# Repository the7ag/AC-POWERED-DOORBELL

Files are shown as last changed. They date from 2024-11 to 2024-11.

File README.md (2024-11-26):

# ESP32 AC Powered with Node.js API to data log

This project uses an **ESP32** microcontroller to send signal data (when a digital pin goes HIGH) to a **Node.js** backend API. The backend uses **MongoDB** to store user data and the signal data. The ESP32 device sends the data to the server only when the signal on a specific pin goes HIGH, with API key-based authentication.

## Table of Contents
- [Project Overview](#project-overview)
- [Hardware Requirements](#hardware-requirements)
- [Software Requirements](#software-requirements)
- [Project Setup](#project-setup)
- [Backend API Structure](#backend-api-structure)
- [ESP32 Setup](#esp32-setup)
- [Database Schema](#database-schema)
- [API Endpoints](#api-endpoints)
- [Testing](#testing)
- [Images](#images)

## Project Overview
This project allows you to authenticate a user and send digital signal data from the ESP32 to a backend server using an API key. When the pin state of a digital input (connected to pin 13) goes HIGH, the ESP32 sends a POST request to the backend API with a timestamp and pin state.

The backend server:
1. Validates the API key sent with each request.
2. Stores signal data in the **SignalData** collection in MongoDB.
3. Associates the data with a user based on their **unique ID** and **API key**.

## Hardware Requirements
- **ESP32 Development Board**
- **Jumper wires** for connecting to external pins
- A breadboard (optional)

### Connections:
- **Pin 13**: Connected to a digital signal source (e.g., a button or sensor)

## Software Requirements
- **Arduino IDE** with the ESP32 board package installed
- **Node.js** and **npm** for running the backend server
- **MongoDB** (local or cloud) to store user and signal data
- **Arduino JSON** library for handling JSON data in the ESP32

## Project Setup

### 1. Clone the Repository
Clone the repository to your local machine:
```bash
git clone https://github.com/yourusername/esp32-signal-data-logger.git
```

### 2. Set Up the Backend API

#### Backend Requirements:
- **Node.js** and **npm** installed
- **MongoDB** running locally or using a cloud service (e.g., MongoDB Atlas)

To set up the backend:
1. Navigate to the `backend` directory:
   ```bash
   cd backend
   ```

2. Install the required dependencies:
   ```bash
   npm install
   ```

3. Start the backend server:
   ```bash
   npm start
   ```

The backend API will be accessible at `http://localhost:5000`.

### 3. Set Up the ESP32

#### ESP32 Code:
1. Open the Arduino IDE and set the board to **ESP32**.
2. Install the **ArduinoJson** library using the Library Manager.
3. Open the ESP32 code, modify the Wi-Fi credentials and backend URL as needed.
4. Upload the code to the ESP32.

### 4. Configure MongoDB
Ensure that MongoDB is running, and update the database connection settings in the backend code (if necessary).

## Backend API Structure

The backend consists of two main collections in MongoDB:
1. **Users**: Stores the user's `uniqueID` and their `apiKey`.
2. **SignalData**: Stores the signal data, including the `timestamp` and `pinState`, linked to the user by their `uniqueID`.

### Database Models:
#### User Schema:
- **uniqueID**: A unique identifier for each user (e.g., from ESP32).
- **apiKey**: A unique API key for the user.

#### SignalData Schema:
- **userID**: The `uniqueID` of the user who owns the signal data.
- **timestamp**: The timestamp when the pin state went HIGH.
- **pinState**: The state of the pin (HIGH/LOW).

## API Endpoints

### 1. **Authentication (POST /auth)**
- **Description**: Authenticates the user and returns an API key.
- **Request Body**:
  ```json
  {
    "unique_id": "USER_UNIQUE_ID"
  }
  ```
- **Response**:
  ```json
  {
    "api_key": "USER_API_KEY"
  }
  ```

### 2. **Save Signal Data (POST /data)**
- **Description**: Saves the signal data when the pin goes HIGH.
- **Request Headers**:
  - **API-Key**: The user's API key.
- **Request Body**:
  ```json
  {
    "timestamp": "timestamp_value",
    "pin_state": "HIGH"
  }
  ```
- **Response**:
  ```json
  {
    "message": "Signal data saved successfully"
  }
  ```

## Testing

### 1. Testing the API:
You can use tools like **Postman** or **curl** to test the API endpoints.

- **Authenticate User**: Send a `POST` request to `/auth` with the `unique_id`.
- **Submit Signal Data**: Send a `POST` request to `/data` with the API key in the headers and the signal data in the body.

### 2. Testing the ESP32:
- Once the ESP32 is running, it will automatically connect to the Wi-Fi, authenticate with the backend, and send signal data when the digital pin goes HIGH.

## Images

### 1. ESP32 Pin Connection Diagram

### 2. Entire Board


## License
This project is licensed under the MIT License - see the [LICENSE](./LICENSE) file for details.

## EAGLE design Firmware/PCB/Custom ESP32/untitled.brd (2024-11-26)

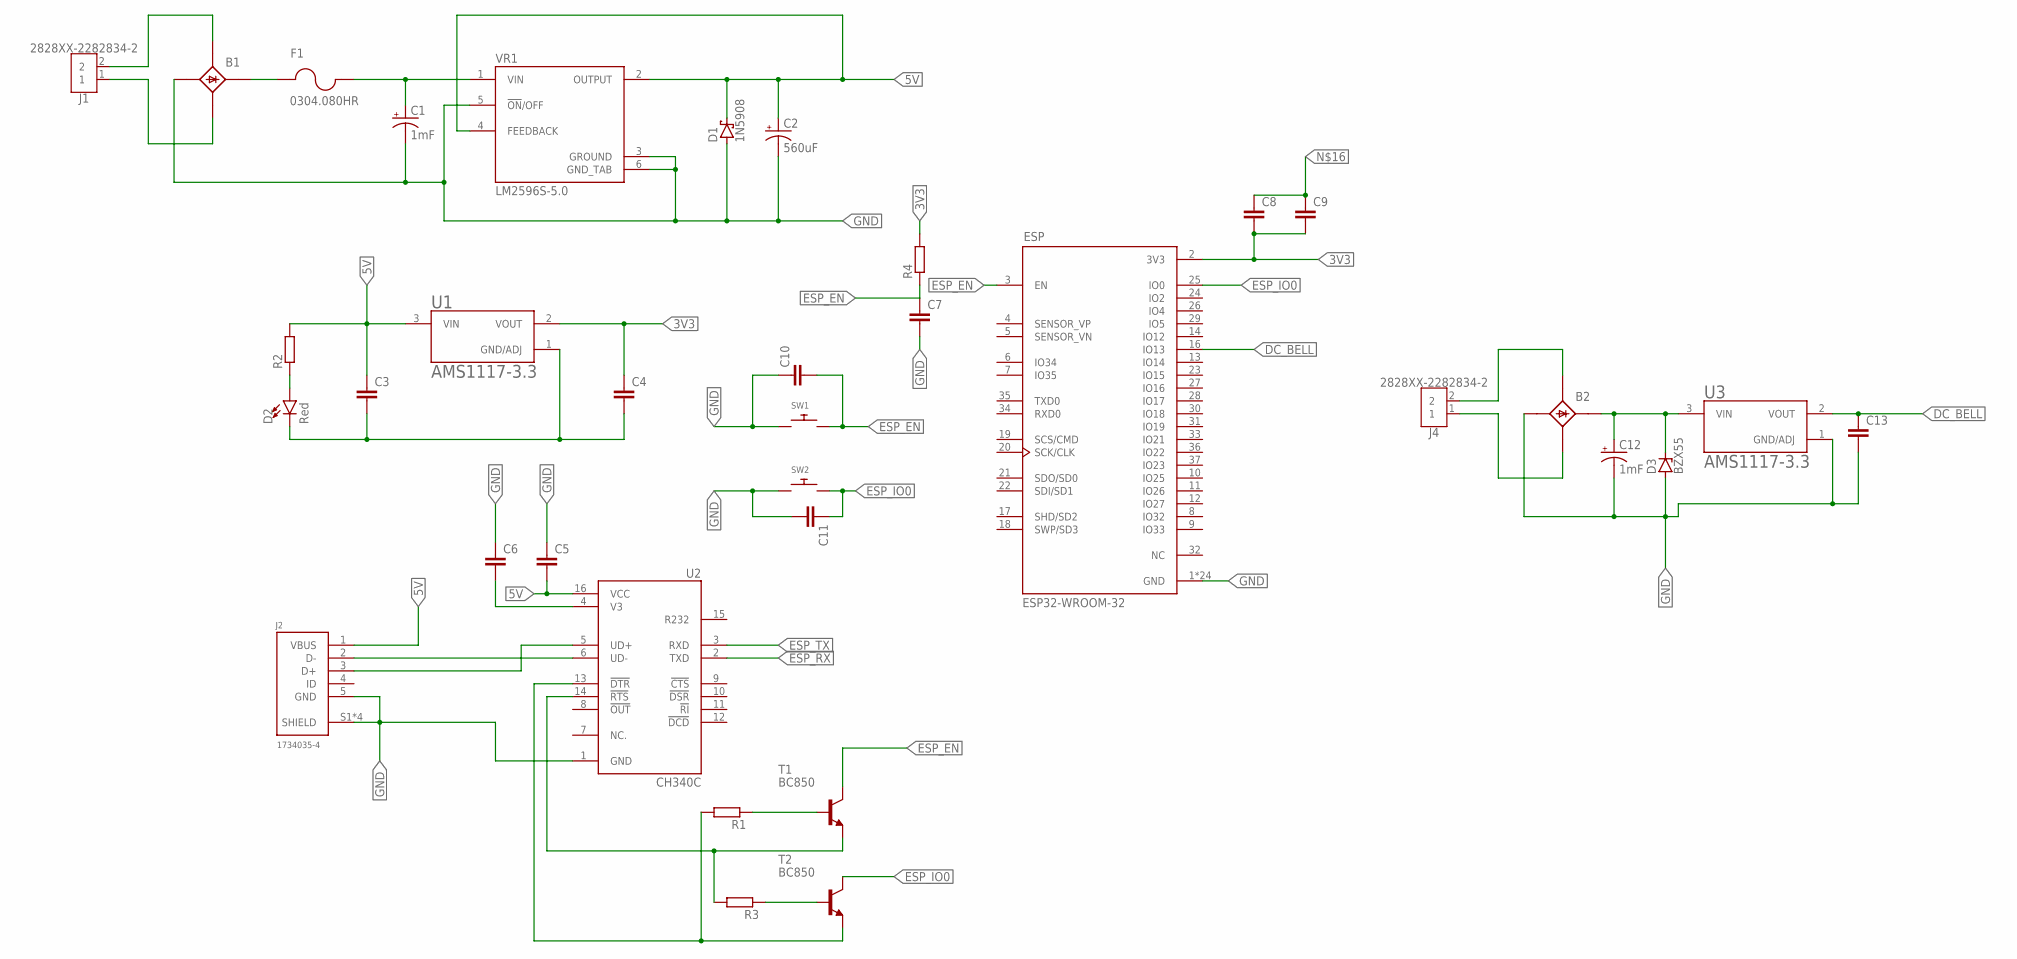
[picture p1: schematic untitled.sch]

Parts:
B1, B2: B25A-
C1, C12: 1mF; CPOL-RADIAL-5MM-10MM
C2: 560uF; PANASONIC_G
C3, C4, C5, C6, C7, C8, C9, C10, C11, C13: C-EUC1206K; C1206K
D1: 1N5908; C4111-15
D2: Red; LED-0603
D3: BZX55; DO35Z10
ESP: ESP32-WROOM-32; MODULE_ESP32-WROOM-32
F1: 0304.080HR
J1, J4: 2828XX-2282834-2; TERMBLK_254-2N
J2: 1734035-4
R1, R2, R3, R4: R-EU_R5025W; R5025W
SW1, SW2: SWITCH_PUSHBUTTONSOFTTOUCHSMD_SJ; PUSHBUTTON_SMD_SJ
T1, T2: BC850; SOT23
U1, U3: AMS1117-3.3; SOT229P700X180-4N
U2: CH340C; SOIC127P600X180-16N
VR1: LM2596S-5.0; TO170P1524X483-6N

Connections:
3V3: C4.1, C8.2, C9.2, ESP.2 (3V3), R4.2, U1.2 (VOUT)
5V: C2.+, C3.1, C5.2, D1.C, J2.1 (VBUS), R2.2, U1.3 (VIN), U2.16 (VCC), VR1.2 (OUTPUT), VR1.4 (FEEDBACK)
DC_BELL: C13.1, ESP.16 (IO13), U3.2 (VOUT)
ESP_EN: C7.1, C10.2, ESP.3 (EN), R4.1, SW1.P$2, T1.3 (C)
ESP_IO0: C11.1, ESP.25 (IO0), SW2.P$2, T2.3 (C)
ESP_RX: U2.2 (TXD)
ESP_TX: U2.3 (RXD)
GND: B1.-1 (-), B2.-1 (-), C1.-, C2.-, C5.1, C6.1, C7.2, C10.1, C11.2, C12.-, C13.2, D1.A, D3.A, ESP.1 (GND), ESP.15 (GND), ESP.38 (GND), ESP.39_1 (GND), ESP.39_2 (GND), ESP.39_3 (GND), ESP.39_4 (GND), ESP.39_5 (GND), ESP.39_6 (GND), ESP.39_7 (GND), ESP.39_8 (GND), ESP.39_9 (GND), ESP.39_10 (GND), ESP.39_11 (GND), ESP.39_12 (GND), ESP.39_13 (GND), ESP.39_14 (GND), ESP.39_15 (GND), ESP.39_16 (GND), ESP.39_17 (GND), ESP.39_18 (GND), ESP.39_19 (GND), ESP.39_20 (GND), ESP.39_21 (GND), J2.5 (GND), J2.S1 (SHIELD), J2.S2 (SHIELD), J2.S3 (SHIELD), J2.S4 (SHIELD), SW1.P$1, SW2.P$1, U2.1 (GND), U3.1 (GND/ADJ), VR1.3 (GROUND), VR1.5 (!ON!/OFF), VR1.6 (GND_TAB)
unnamed: B1.AC1- (AC1), J1.2
unnamed: B1.AC2- (AC2), J1.1
unnamed: B1.+1 (+), F1.1
unnamed: C1.+, F1.2, VR1.1 (VIN)
unnamed: D2.A, R2.1
unnamed: C3.2, C4.2, D2.C, U1.1 (GND/ADJ)
unnamed: J2.3 (D+), U2.5 (UD+)
unnamed: J2.2 (D-), U2.6 (UD-)
unnamed: B2.AC1- (AC1), J4.2
unnamed: B2.AC2- (AC2), J4.1
unnamed: C6.2, U2.4 (V3)
unnamed: R1.1, T1.1 (B)
unnamed: R3.1, T2.1 (B)
unnamed: R3.2, T1.2 (E), U2.14 (!RTS)
unnamed: R1.2, T2.2 (E), U2.13 (!DTR)
unnamed: C8.1, C9.1
unnamed: B2.+1 (+), C12.+, D3.C, U3.3 (VIN)

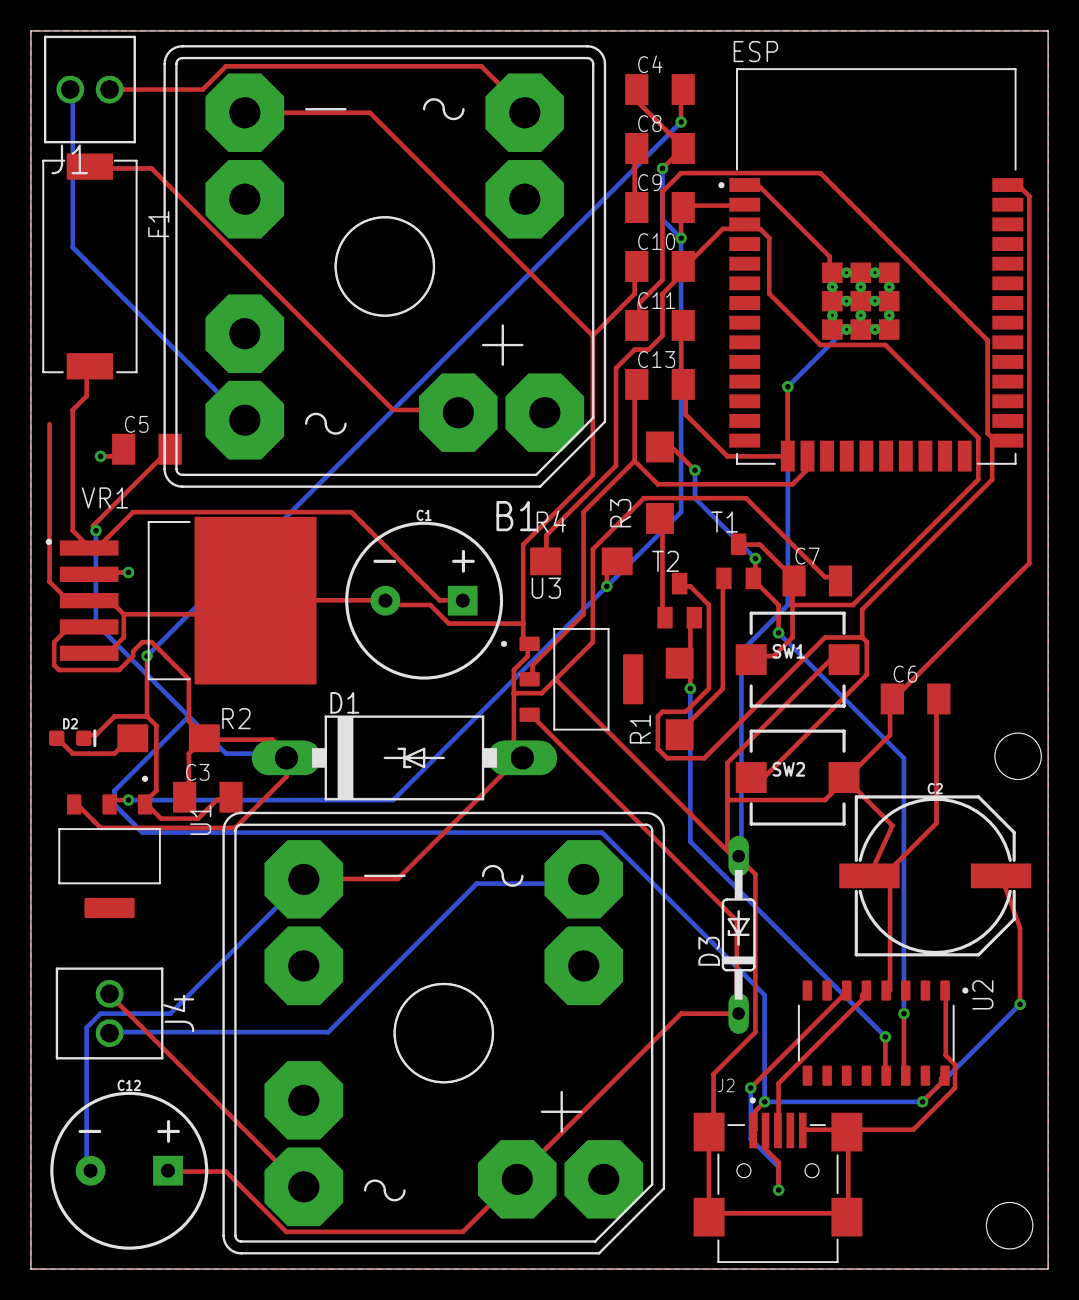
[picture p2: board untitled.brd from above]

Board: 2 copper layers, 65.7 x 80.0 mm, 35 parts (0 on the bottom side), 23 nets.

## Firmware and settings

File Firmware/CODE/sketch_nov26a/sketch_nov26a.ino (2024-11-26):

#include <WiFi.h>
#include <HTTPClient.h>
#include <ArduinoJson.h>
#include "time.h"
#include <esp_sleep.h>

const char* ssid = "your_wifi_ssid";
const char* password = "your_wifi_password";

const char* authURL = "http://192.168.1.1:5000/auth";
const char* dataURL = "http://192.168.1.1:5000/data";

const char* ntpServer = "pool.ntp.org";
const long gmtOffset_sec = 2 * 3600;
const int daylightOffset_sec = 0;

#define SIGNAL_PIN 13

RTC_DATA_ATTR String apiKey = "";
RTC_DATA_ATTR bool authenticated = false;

/**
 * @brief Sets up the ESP32 microcontroller
 * 
 * This function initializes the ESP32 board by setting up the serial port, 
 * setting the pin mode for the signal pin, and enabling the external wake-up 
 * feature using the esp_sleep_enable_ext0_wakeup function. It also calls the 
 * setupTime function to set up the time and authenticate the device using the 
 * authenticate function. If authentication fails, it prints an error message to the serial port.
 * Finally, it sends a POST request to the server using the sendPostRequest function and enters deep sleep.
 */
void setup() {
  Serial.begin(115200);
  pinMode(SIGNAL_PIN, INPUT_PULLDOWN);

  // Check if esp_sleep_enable_ext0_wakeup is available
  if (&esp_sleep_enable_ext0_wakeup != nullptr) {
    esp_sleep_enable_ext0_wakeup(GPIO_NUM_13, HIGH);
  } else {
    Serial.println("Error: esp_sleep_enable_ext0_wakeup is null");
    return;
  }

  try {
    if (!authenticated) {
      connectToWiFi();
      setupTime();
      authenticate();
    } else {
      sendPostRequest();
    }
  } catch (const std::exception& e) {
    Serial.print("Exception: ");
    Serial.println(e.what());
    return;
  } catch (...) {
    Serial.println("Unknown error occurred");
    return;
  }

  enterDeepSleep();
}

void loop() {}

/**
 * @brief Connects to the WiFi network
 * 
 * This function attempts to connect to a WiFi network using the provided SSID
 * and password. It prints an error message to the serial port if the SSID or
 * password is null. It also prints an error message if the connection attempt
 * fails after a certain number of attempts.
 */
void connectToWiFi() {
  // Check if the SSID or password is null
  if (ssid == nullptr || password == nullptr) {
    Serial.println("Error: SSID or password is null");
    return;
  }

  // Attempt to connect to the WiFi network
  WiFi.begin(ssid, password);

  int attempts = 0;
  const int maxAttempts = 20;

  // Wait for the connection to be established or max attempts reached
  while (WiFi.status() != WL_CONNECTED && attempts < maxAttempts) {
    delay(500);
    attempts++;
  }

  // Check if the connection was established
  if (WiFi.status() != WL_CONNECTED) {
    Serial.println("Error: Failed to connect to WiFi");
    return;
  }

  Serial.println("Connected to WiFi");
}

/**
 * @brief Sets up the time using NTP server
 * 
 * This function configures the ESP32's internal clock to synchronize with an NTP server. 
 * It checks if the ntpServer is not null before proceeding. If the setup fails, it prints 
 * appropriate error messages to the serial port.
 */
void setupTime() {
  // Check if the NTP server address is provided
  if (ntpServer == nullptr) {
    Serial.println("Error: ntpServer is null");
    return;
  }

  // Configure the time using the specified NTP server and offset values
  configTime(gmtOffset_sec, daylightOffset_sec, ntpServer);

  struct tm timeInfo;
  // Attempt to get the local time
  if (!getLocalTime(&timeInfo)) {
    Serial.println("Error: Failed to get local time");
    return;
  }
}

/**
 * @brief Returns the current time as a string in ISO 8601 format
 * 
 * This function allocates memory for a tm struct and uses the getLocalTime
 * function to fill it with the current time. It then uses strftime to convert
 * the tm struct to a string in ISO 8601 format. Finally, it deallocates the
 * memory and returns the string.
 * 
 * @return String representing the current time in ISO 8601 format
 */
String getCurrentTime() {
  struct tm* timeInfo = new struct tm; // Allocate memory to prevent null pointer references
  if (getLocalTime(timeInfo)) {
    char timeString[25];
    strftime(timeString, sizeof(timeString), "%Y-%m-%dT%H:%M:%S", timeInfo);
    delete timeInfo; // Deallocate memory to prevent memory leaks
    return String(timeString);
  }
  delete timeInfo; // Deallocate memory to prevent memory leaks
  return "N/A";
}

/**
 * @brief Returns the unique ID as a string of the device's MAC address
 * 
 * This function retrieves the MAC address of the ESP32 board and converts it
 * to a string in hexadecimal format. The string is then returned as the unique
 * ID of the device.
 * 
 * @return String representing the unique ID of the device
 */
String getUniqueID() {
  uint8_t mac[6];

  // Check if WiFi is null
  if (WiFi == nullptr) {
    Serial.println("Error: WiFi is null");
    return "";
  }

  // Check if WiFi.macAddress is null
  if (WiFi.macAddress == nullptr) {
    Serial.println("Error: WiFi.macAddress is null");
    return "";
  }

  // Attempt to get the MAC address
  if (!WiFi.macAddress(mac)) {
    Serial.println("Error: Failed to get MAC address");
    return "";
  }

  String macAddress = "";
  for (int i = 0; i < 6; i++) {
    macAddress += String(mac[i], HEX); // Convert each byte to hexadecimal
  }

  // Make the MAC address string uppercase for consistency
  macAddress.toUpperCase();
  return macAddress;
}

/**
 * @brief Authenticates the device and retrieves an API key
 * 
 * This function sends a POST request to the authentication URL with the
 * unique ID of the device. It retrieves the API key from the response and
 * stores it in the global apiKey variable. It also sets the authenticated
 * flag to true.
 * 
 * @return void
 */
void authenticate() {
  HTTPClient http;
  http.begin(authURL);
  http.addHeader("Content-Type", "application/json");

  String uniqueID = getUniqueID();

  // Check if uniqueID is empty
  if (uniqueID == "") {
    Serial.println("Error: Unique ID is empty");
    return;
  }

  StaticJsonDocument<200> doc;
  doc["unique_id"] = uniqueID;

  String jsonData;
  serializeJson(doc, jsonData);

  int httpResponseCode = http.POST(jsonData);

  // Check for errors
  if (httpResponseCode <= 0) {
    Serial.print("Error: ");
    Serial.println(http.errorString(httpResponseCode));
    return;
  }

  String response = http.getString();

  // Check if response is empty
  if (response == "") {
    Serial.println("Error: Response is empty");
    return;
  }

  StaticJsonDocument<200> responseDoc;
  DeserializationError error = deserializeJson(responseDoc, response);

  // Check for deserialization errors
  if (error) {
    Serial.print("Deserialization error: ");
    Serial.println(error.c_str());
    return;
  }

  // Check if api_key is present in the response
  if (!responseDoc.containsKey("api_key")) {
    Serial.println("Error: Response does not contain an API key");
    return;
  }

  apiKey = responseDoc["api_key"].as<String>();
  authenticated = true;
}

/**
 * @brief Sends a POST request to the server with the current timestamp and the state of the signal pin
 * 
 * This function sends a POST request to the server with the current timestamp and the state of the signal pin. 
 * It checks if the apiKey is not null before adding the Authorization header to the HTTP request. 
 * It also checks if SIGNAL_PIN is not null before reading its state and adding it to the JSON document. 
 * Finally, it catches any exceptions that may occur during the execution of the function.
 */
void sendPostRequest() {
  if (WiFi.status() != WL_CONNECTED) {
    connectToWiFi();
  }

  HTTPClient http;
  http.begin(dataURL);
  http.addHeader("Content-Type", "application/json");

  // Check if apiKey is not null
  if (apiKey == nullptr) {
    Serial.println("Error: apiKey is null");
    return;
  }
  http.addHeader("Authorization", "Bearer " + apiKey);

  StaticJsonDocument<200> doc;
  doc["timestamp"] = getCurrentTime();

  // Check if SIGNAL_PIN is not null
  if (SIGNAL_PIN == nullptr) {
    Serial.println("Error: SIGNAL_PIN is null");
    return;
  }
  doc["pin_state"] = digitalRead(SIGNAL_PIN) ? "HIGH" : "LOW";

  String jsonData;
  serializeJson(doc, jsonData);

  try {
    int httpResponseCode = http.POST(jsonData);
    if (httpResponseCode <= 0) {
      Serial.print("Error: ");
      Serial.println(http.errorString(httpResponseCode));
    }
  } catch (const std::exception& e) {
    Serial.print("Exception: ");
    Serial.println(e.what());
  } catch (...) {
    Serial.println("Unknown error occurred");
  }

  http.end();
}

/**
 * @brief Puts the ESP32 into deep sleep
 * 
 * This function attempts to put the ESP32 into deep sleep mode using the
 * esp_deep_sleep_start function. If the function is null, it prints an error
 * message to the serial port. It also catches any exceptions that may occur
 * during the execution of the function.
 */
void enterDeepSleep() {
  try {
    // Check if esp_deep_sleep_start is not null
    if (esp_deep_sleep_start != nullptr) {
      delay(100); // Wait for a short period of time before entering deep sleep
      esp_deep_sleep_start(); // Enter deep sleep
    } else {
      Serial.println("Error: esp_deep_sleep_start is null");
    }
  } catch (const std::exception& e) {
    Serial.print("Exception: ");
    Serial.println(e.what()); // Print the exception message
  } catch (...) {
    Serial.println("Unknown error occurred");
  }
}

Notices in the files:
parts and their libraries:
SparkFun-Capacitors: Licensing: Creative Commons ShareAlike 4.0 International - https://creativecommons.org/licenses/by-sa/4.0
